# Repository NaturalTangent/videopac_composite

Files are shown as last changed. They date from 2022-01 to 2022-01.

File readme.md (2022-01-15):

# Videopac G7000 Composite Video

This is a PCB providing composite video amplification for a PAL VideoPac G7000.

Created using kicad 6.0.0

## Schematic

The schematic is copied from https://gamesx.com/wiki/doku.php?id=av:g7000_av

schematic Schematic

## PCB

The PCB measures 60.5mm X 23.5mm.

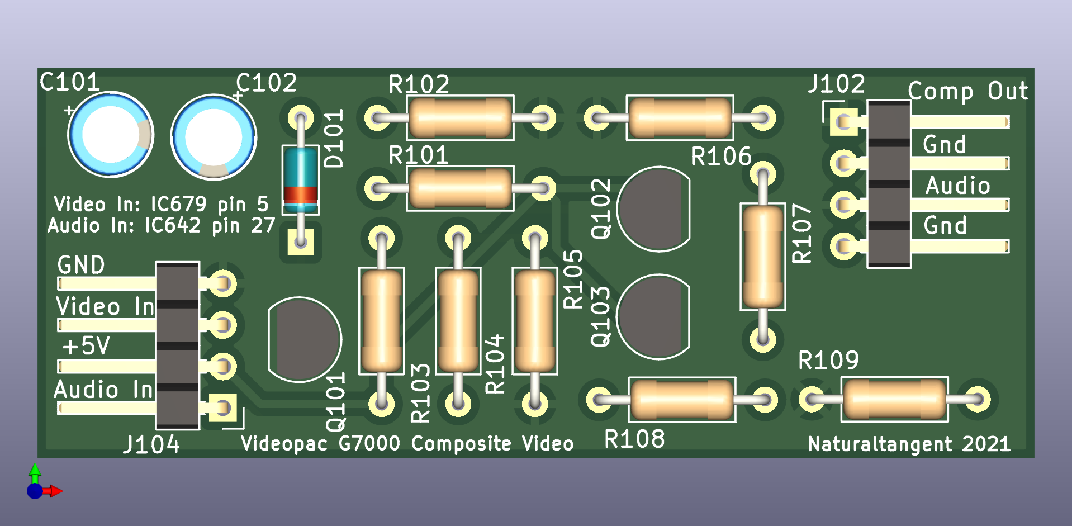
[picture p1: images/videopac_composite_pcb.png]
PCB


## BOM

[videopac_rgb_bom.csv](videopac_composite_bom.csv "BOM")

## Installation

Check the schematic for your variant of Videopac PCB, I'm led to believe that different revisions have different IC references and locations.

On the revision I tested with the IC are located as illustrated below (I desoldered the shield to access IC679 to confirm its identity, it's not essntial to do this);

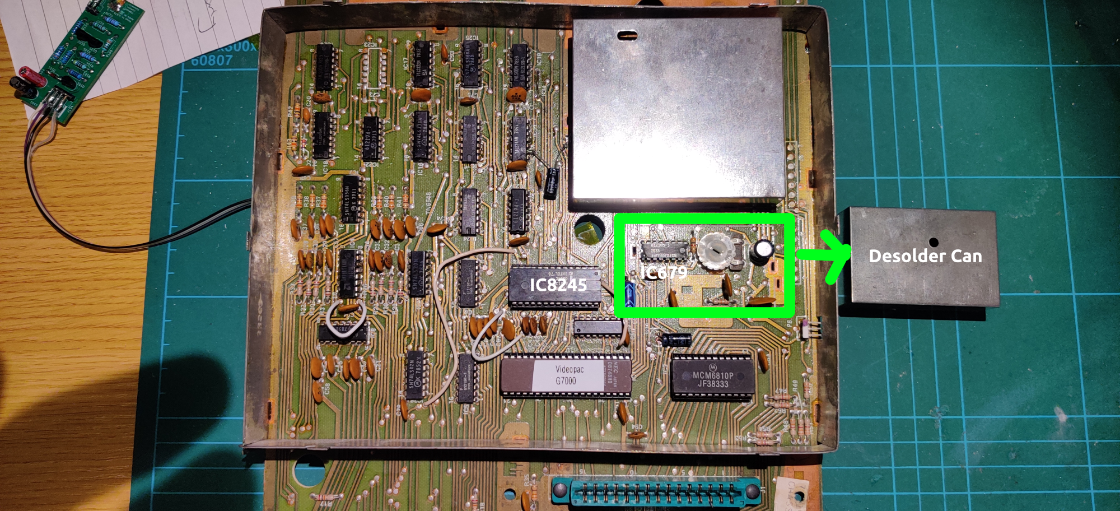
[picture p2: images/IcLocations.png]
IC Locations


Viewing from the top of the PCB, the location of the input pins are illustrated below;

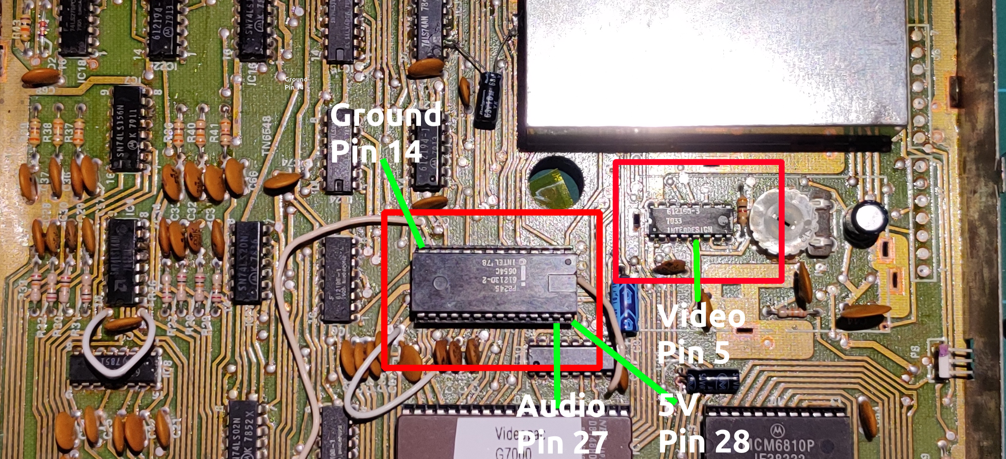
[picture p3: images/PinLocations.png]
Pin Locations


I soldered to the bottom of the board as shown below;

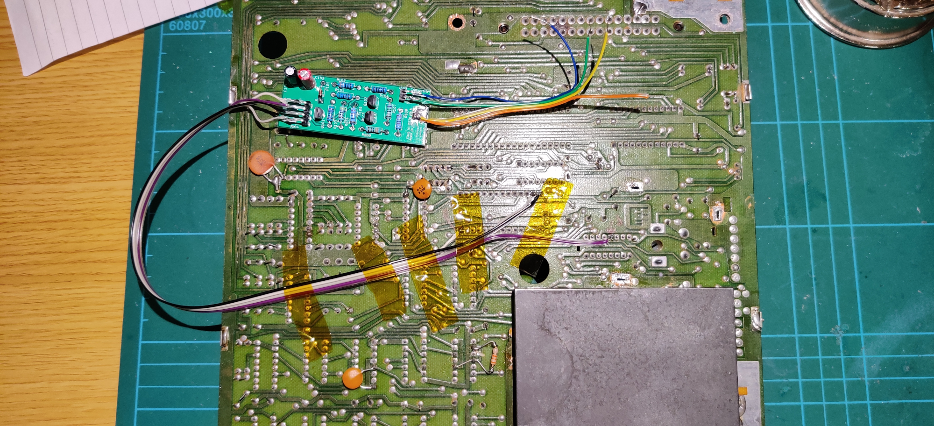
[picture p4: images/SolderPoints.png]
Solder Points


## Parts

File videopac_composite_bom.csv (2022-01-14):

Id | Designator | Package | Quantity | Designation | Supplier and ref
1 | J102 | PinHeader_1x04_P2.54mm_Horizontal | 1 | Conn_01x04
2 | C101 | CP_Radial_D5.0mm_P2.00mm | 1 | 1u
3 | R108 | R_Axial_DIN0207_L6.3mm_D2.5mm_P10.16mm_Horizontal | 1 | 3k3
4 | Q102 | TO-92_Inline | 1 | BC558
5 | R105 | R_Axial_DIN0207_L6.3mm_D2.5mm_P10.16mm_Horizontal | 1 | 220
6 | R107 | R_Axial_DIN0207_L6.3mm_D2.5mm_P10.16mm_Horizontal | 1 | 75
7 | Q101,Q103 | TO-92_Inline | 2 | BC548
8 | R103 | R_Axial_DIN0207_L6.3mm_D2.5mm_P10.16mm_Horizontal | 1 | 270
9 | C102 | CP_Radial_D5.0mm_P2.00mm | 1 | 10u
10 | R102 | R_Axial_DIN0207_L6.3mm_D2.5mm_P10.16mm_Horizontal | 1 | 3k9
11 | R104 | R_Axial_DIN0207_L6.3mm_D2.5mm_P10.16mm_Horizontal | 1 | 470
12 | R106 | R_Axial_DIN0207_L6.3mm_D2.5mm_P10.16mm_Horizontal | 1 | 1k
13 | D101 | D_DO-35_SOD27_P7.62mm_Horizontal | 1 | 1N4148
14 | R109 | R_Axial_DIN0207_L6.3mm_D2.5mm_P10.16mm_Horizontal | 1 | 1k2
15 | R101 | R_Axial_DIN0207_L6.3mm_D2.5mm_P10.16mm_Horizontal | 1 | 5k6
16 | J104 | PinHeader_1x04_P2.54mm_Horizontal | 1 | Composite Input

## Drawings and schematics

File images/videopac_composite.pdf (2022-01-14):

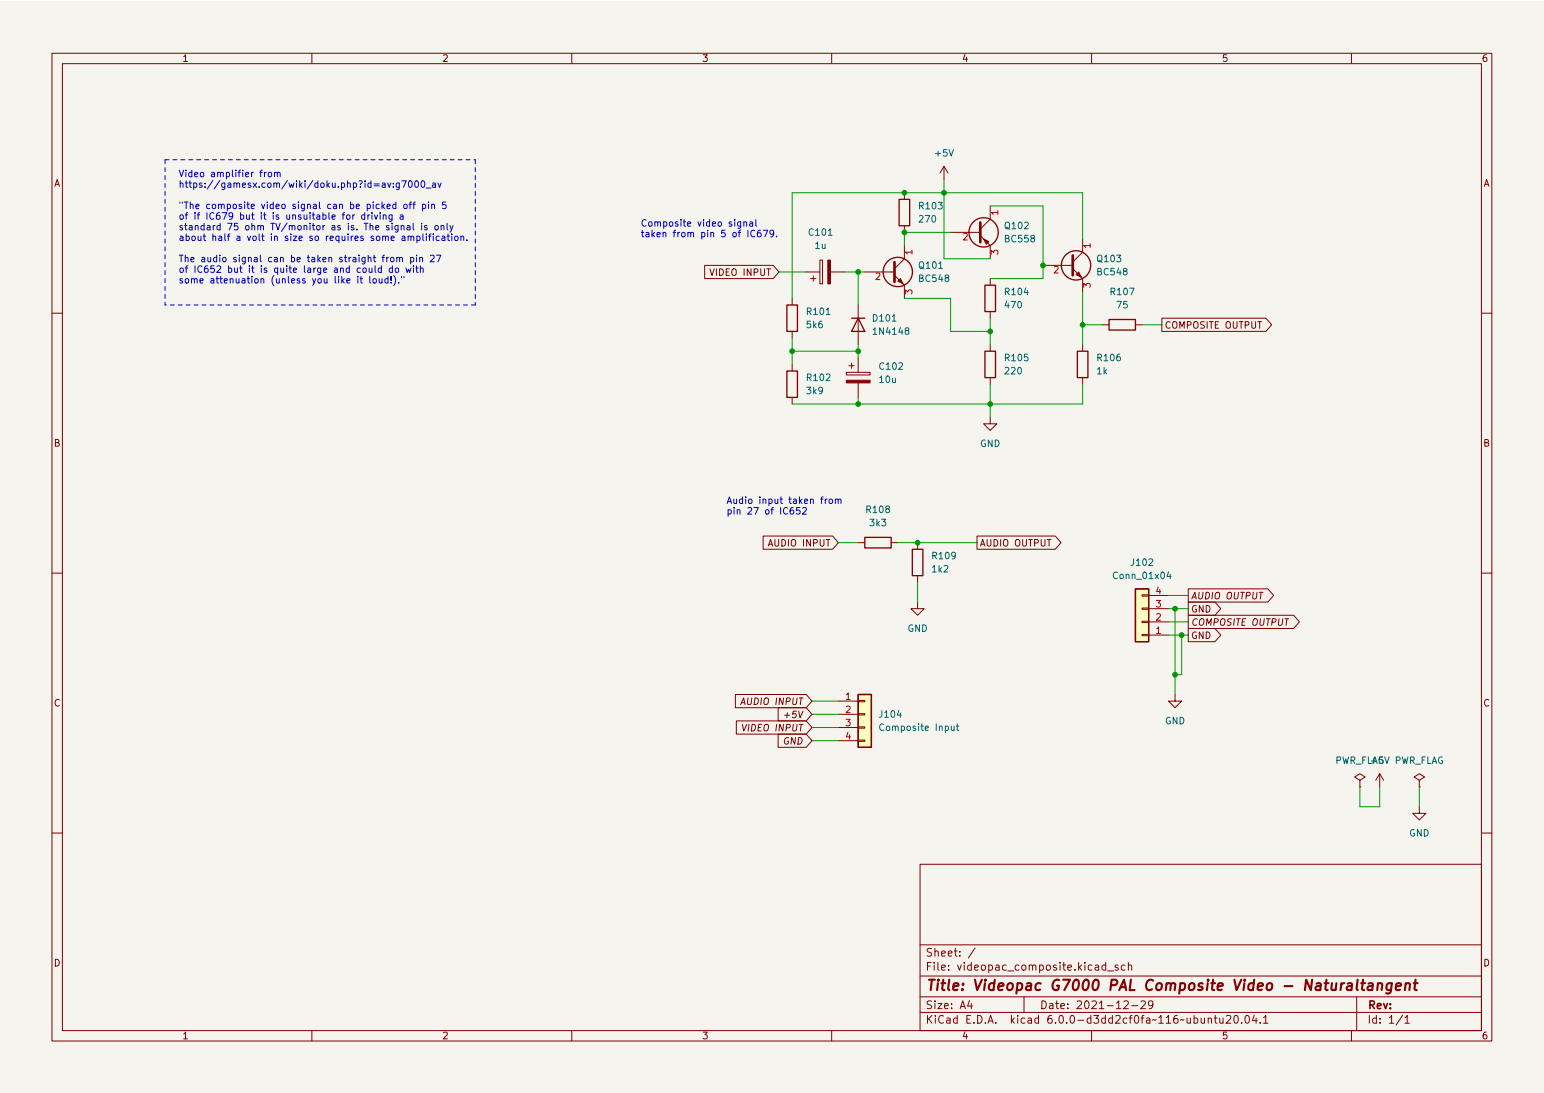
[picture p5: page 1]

COMPOSITE OUTPUT COMPOSITE OUTPUT GND
File: videopac_composite.kicad_sch Sheet: / R108

VIDEO INPUT VIDEO INPUT AUDIO INPUT Video amplifier from
https://gamesx.com/wiki/doku.php?id=av:g7000_av

"The composite video signal can be picked off pin 5
of if IC679 but it is unsuitable for driving a
standard 75 ohm TV/monitor as is. The signal is only
about half a volt in size so requires some amplification.

Composite video signal
taken from pin 5 of IC679.

The audio signal can be taken straight from pin 27
of IC652 but it is quite large and could do with
some attenuation (unless you like it loud!)."

Audio input taken from
pin 27 of IC652

AUDIO OUTPUT AUDIO OUTPUT GND

Id: 1/1 Title: Videopac G7000 PAL Composite Video - Naturaltangent

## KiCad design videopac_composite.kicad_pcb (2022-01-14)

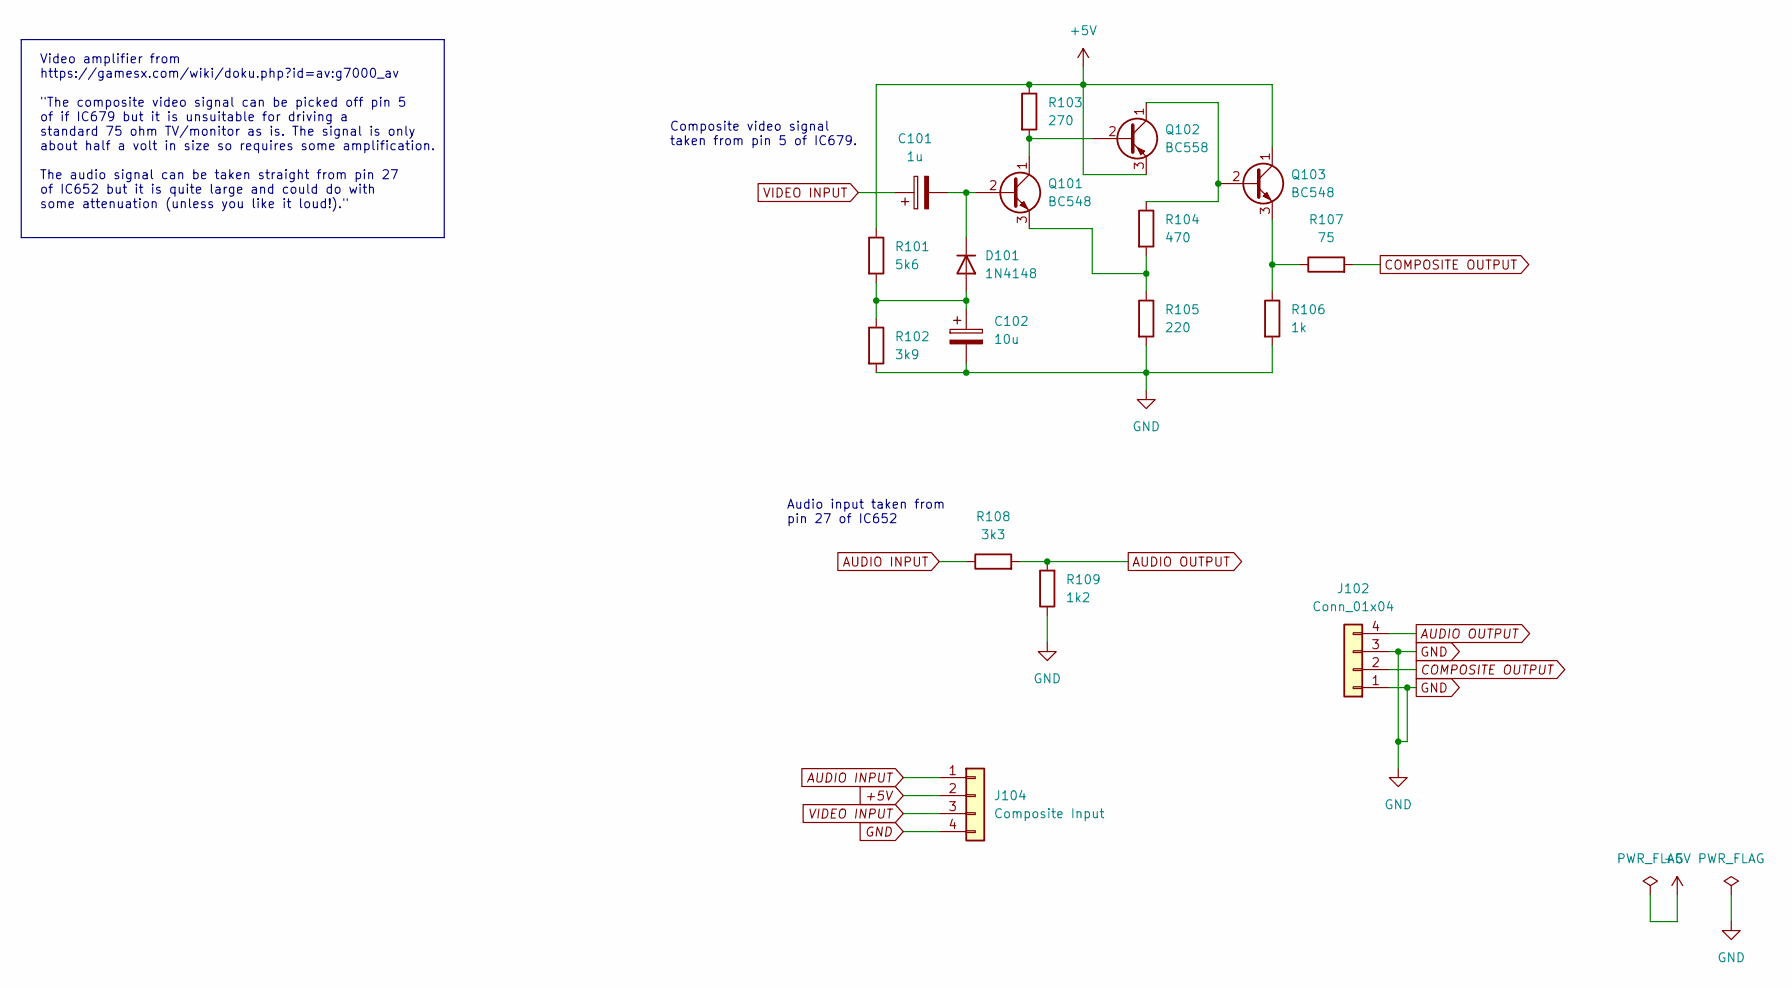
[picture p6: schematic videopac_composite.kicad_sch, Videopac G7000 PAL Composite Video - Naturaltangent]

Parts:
C101: 1u; CP_Radial_D5.0mm_P2.00mm
C102: 10u; CP_Radial_D5.0mm_P2.00mm
D101: 1N4148; D_DO-35_SOD27_P7.62mm_Horizontal
J102: Conn_01x04; PinHeader_1x04_P2.54mm_Horizontal
J104: Composite Input; PinHeader_1x04_P2.54mm_Horizontal
Q101, Q103: BC548; TO-92_Inline
Q102: BC558; TO-92_Inline
R101: 5k6; R_Axial_DIN0207_L6.3mm_D2.5mm_P10.16mm_Horizontal
R102: 3k9; R_Axial_DIN0207_L6.3mm_D2.5mm_P10.16mm_Horizontal
R103: 270; R_Axial_DIN0207_L6.3mm_D2.5mm_P10.16mm_Horizontal
R104: 470; R_Axial_DIN0207_L6.3mm_D2.5mm_P10.16mm_Horizontal
R105: 220; R_Axial_DIN0207_L6.3mm_D2.5mm_P10.16mm_Horizontal
R106: 1k; R_Axial_DIN0207_L6.3mm_D2.5mm_P10.16mm_Horizontal
R107: 75; R_Axial_DIN0207_L6.3mm_D2.5mm_P10.16mm_Horizontal
R108: 3k3; R_Axial_DIN0207_L6.3mm_D2.5mm_P10.16mm_Horizontal
R109: 1k2; R_Axial_DIN0207_L6.3mm_D2.5mm_P10.16mm_Horizontal

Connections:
+5V: J104.2, Q102.3 (E), Q103.1 (C), R101.1, R103.1
AUDIO INPUT: J104.1, R108.1
AUDIO OUTPUT: J102.4, R108.2, R109.2
COMPOSITE OUTPUT: J102.2, R107.2
GND: C102.2, J102.1, J102.3, J104.4, R102.2, R105.2, R106.2, R109.1
unnamed: C101.2, D101.1 (K), Q101.2 (B)
unnamed: C102.1, D101.2 (A), R101.2, R102.1
unnamed: Q101.1 (C), Q102.2 (B), R103.2
unnamed: Q101.3 (E), R104.2, R105.1
unnamed: Q102.1 (C), Q103.2 (B), R104.1
unnamed: Q103.3 (E), R106.1, R107.1
VIDEO INPUT: C101.1, J104.3

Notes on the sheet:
Video amplifier from https://gamesx.com/wiki/doku.php?id=av:g7000_av "The composite video signal can be picked off pin 5 of if IC679 but it is unsuitable for driving a standard 75 ohm TV/monitor as is. The signal is only about half a volt in size so requires some amplification. The audio signal can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
Audio input taken from pin 27 of IC652
Composite video signal taken from pin 5 of IC679.

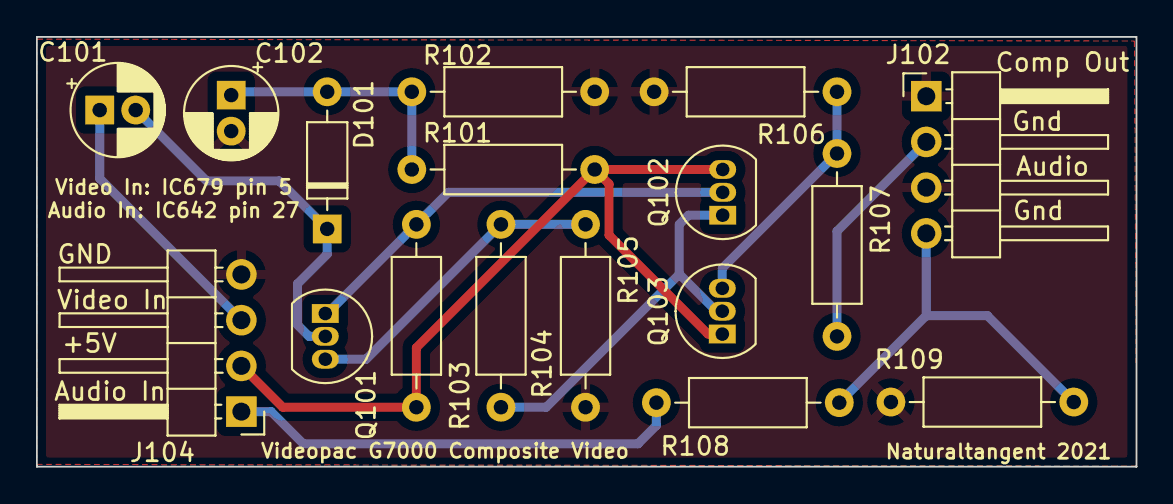
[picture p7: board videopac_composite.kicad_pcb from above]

Board: 2 copper layers, 61.1 x 23.9 mm, 17 parts (0 on the bottom side), 12 nets.

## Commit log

2021-12-31 Initial commit of Philips Videopac G7000 composite amplifier. Untested, waiting for boards to arrive.
    [videopac_composite-B_Cu.gbl, videopac_composite-B_Mask.gbs, videopac_composite-B_Paste.gbp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]
2021-12-31 Added bill of materials.
    [videopac_composite_bom.csv]
2022-01-14 Add additional ground connections.
    [videopac_composite-B_Cu.gbl, videopac_composite-B_Mask.gbs, videopac_composite-B_Paste.gbp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]
